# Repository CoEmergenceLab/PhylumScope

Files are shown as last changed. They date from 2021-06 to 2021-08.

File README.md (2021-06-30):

Banner

# Mechanical Design
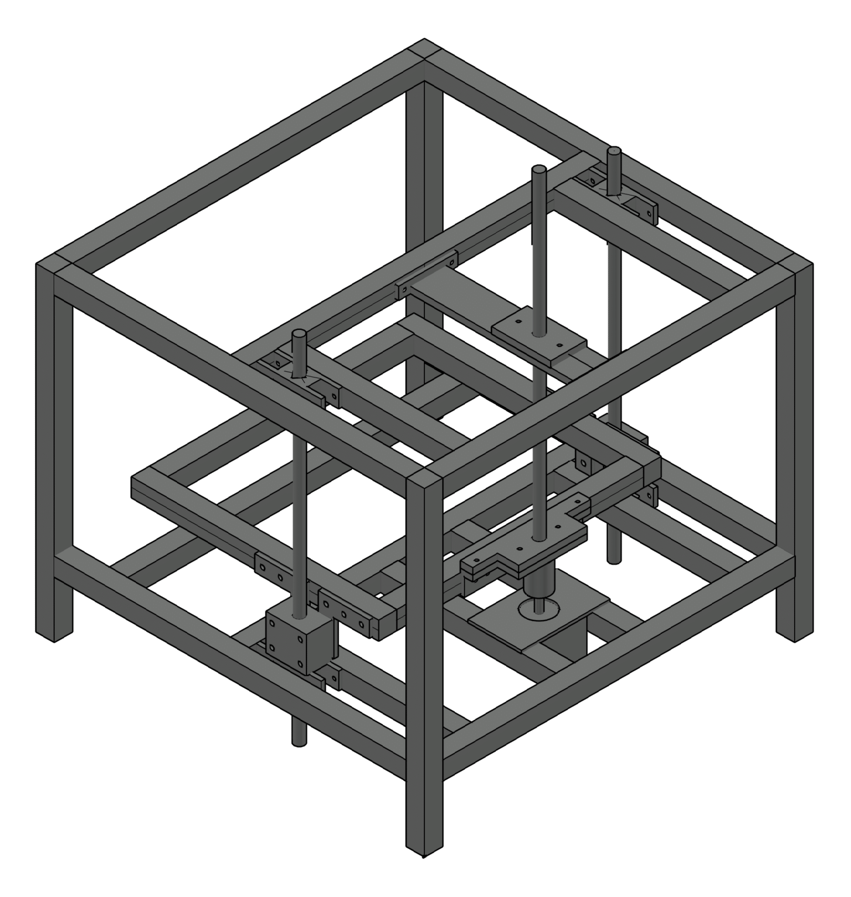
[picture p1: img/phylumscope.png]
Mechanical Design

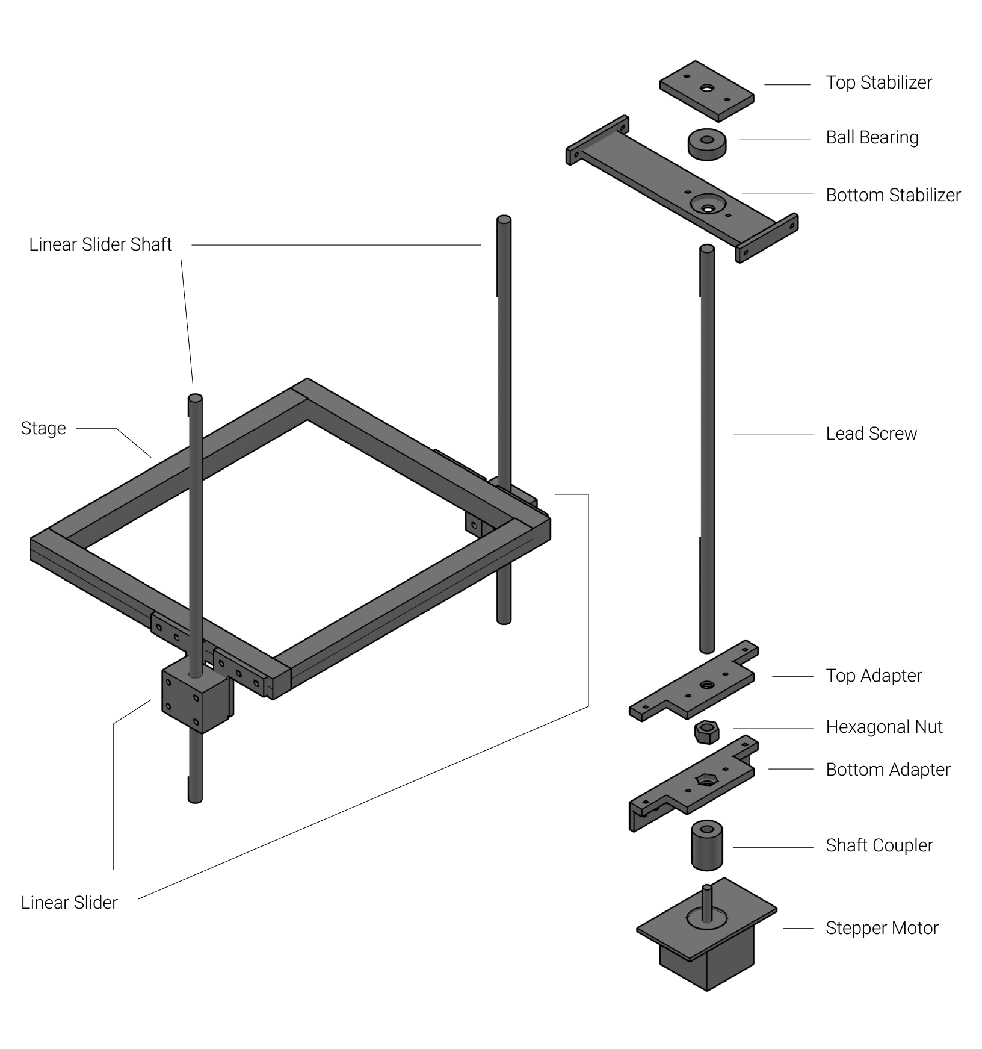
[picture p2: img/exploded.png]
Exploded View


# Electronics
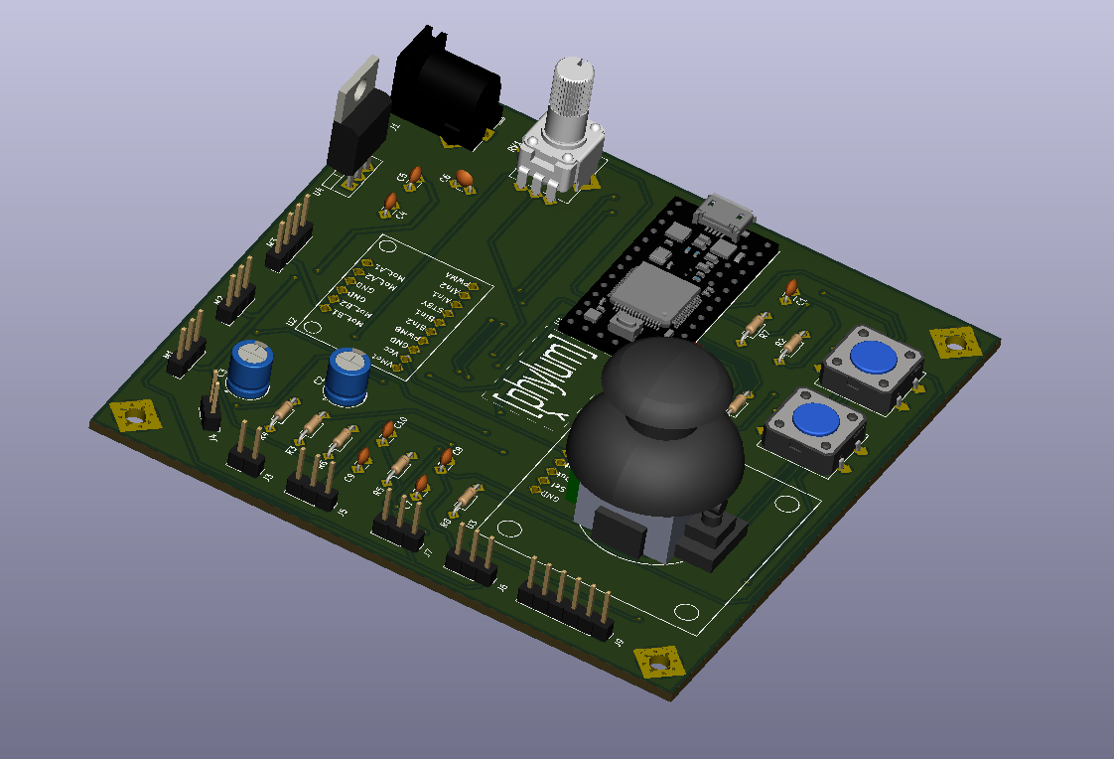
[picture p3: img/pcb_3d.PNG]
3D PCB

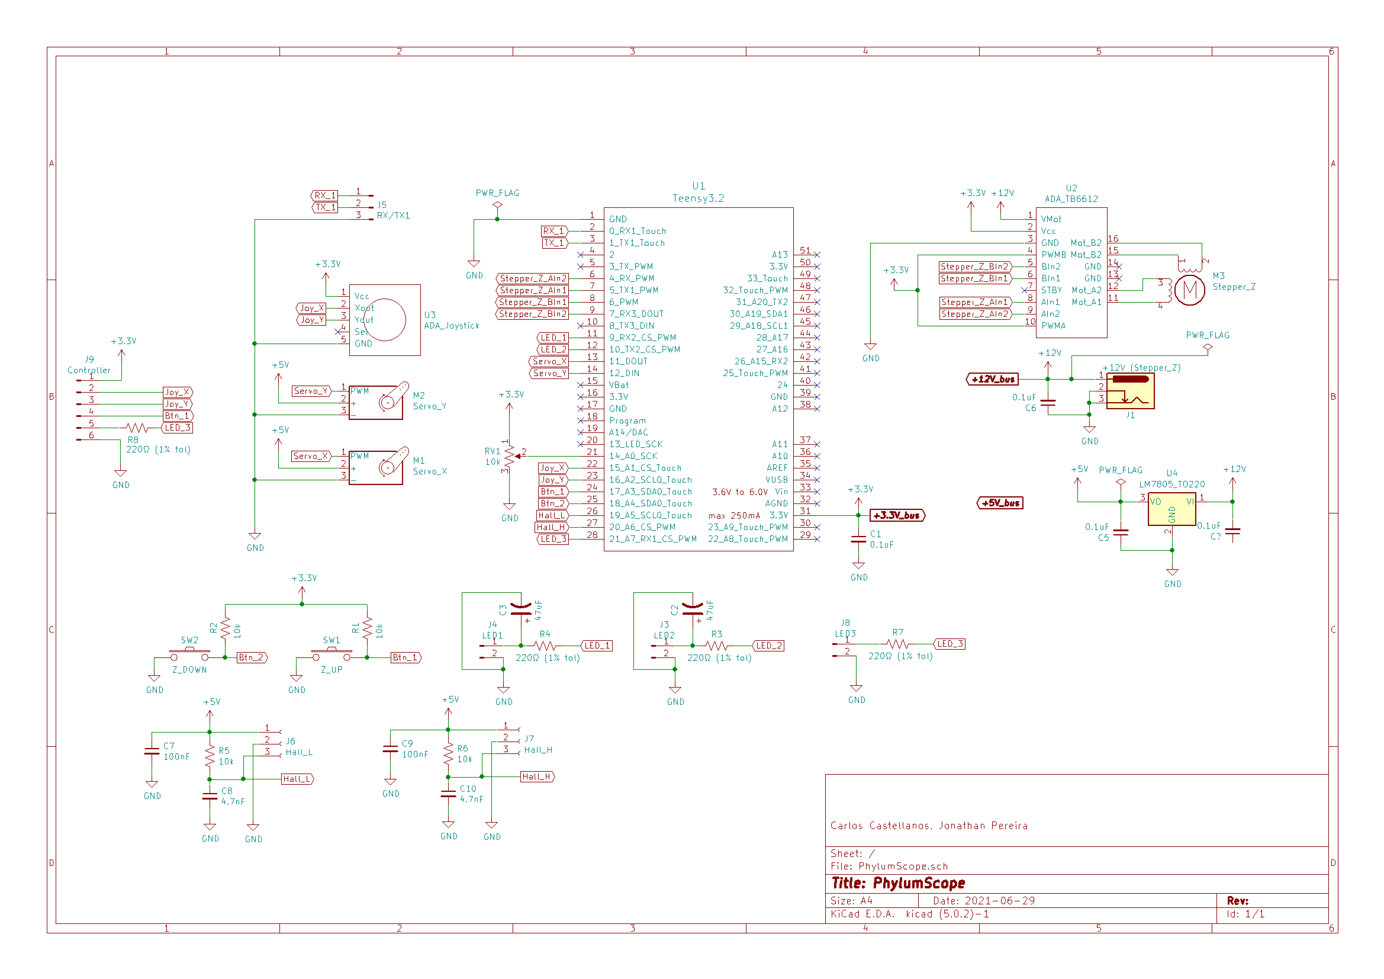
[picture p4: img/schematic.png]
Schematic

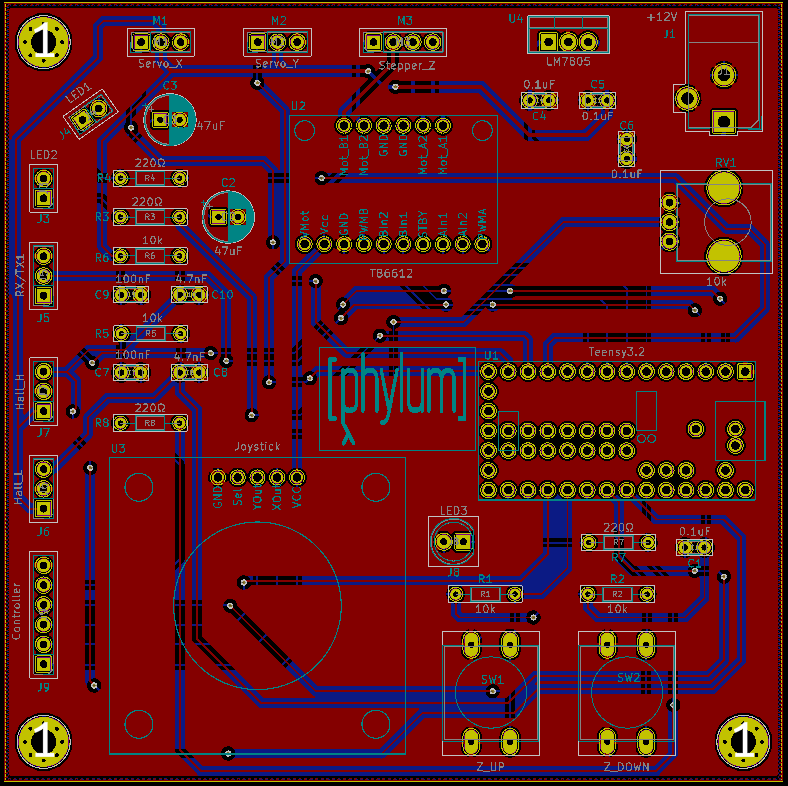
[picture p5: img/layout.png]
Layout


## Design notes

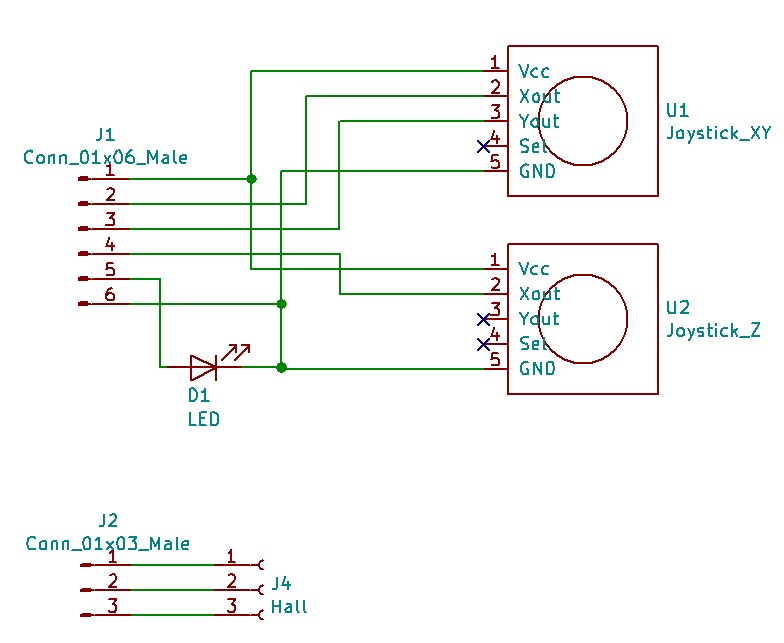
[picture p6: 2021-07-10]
img/breakouts_schematic.png

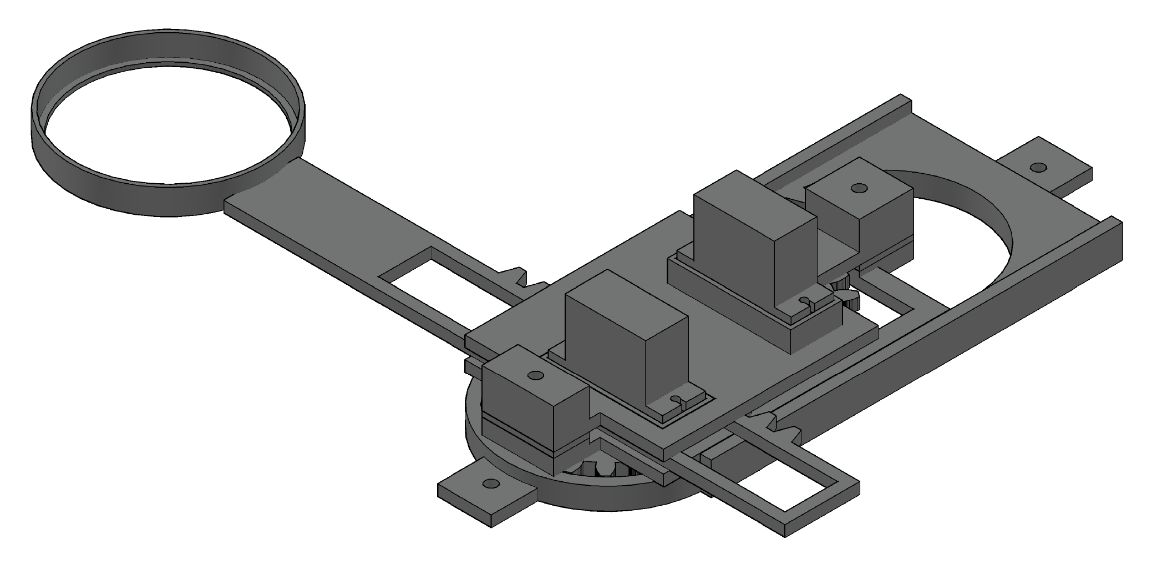
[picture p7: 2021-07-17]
img/xy.png

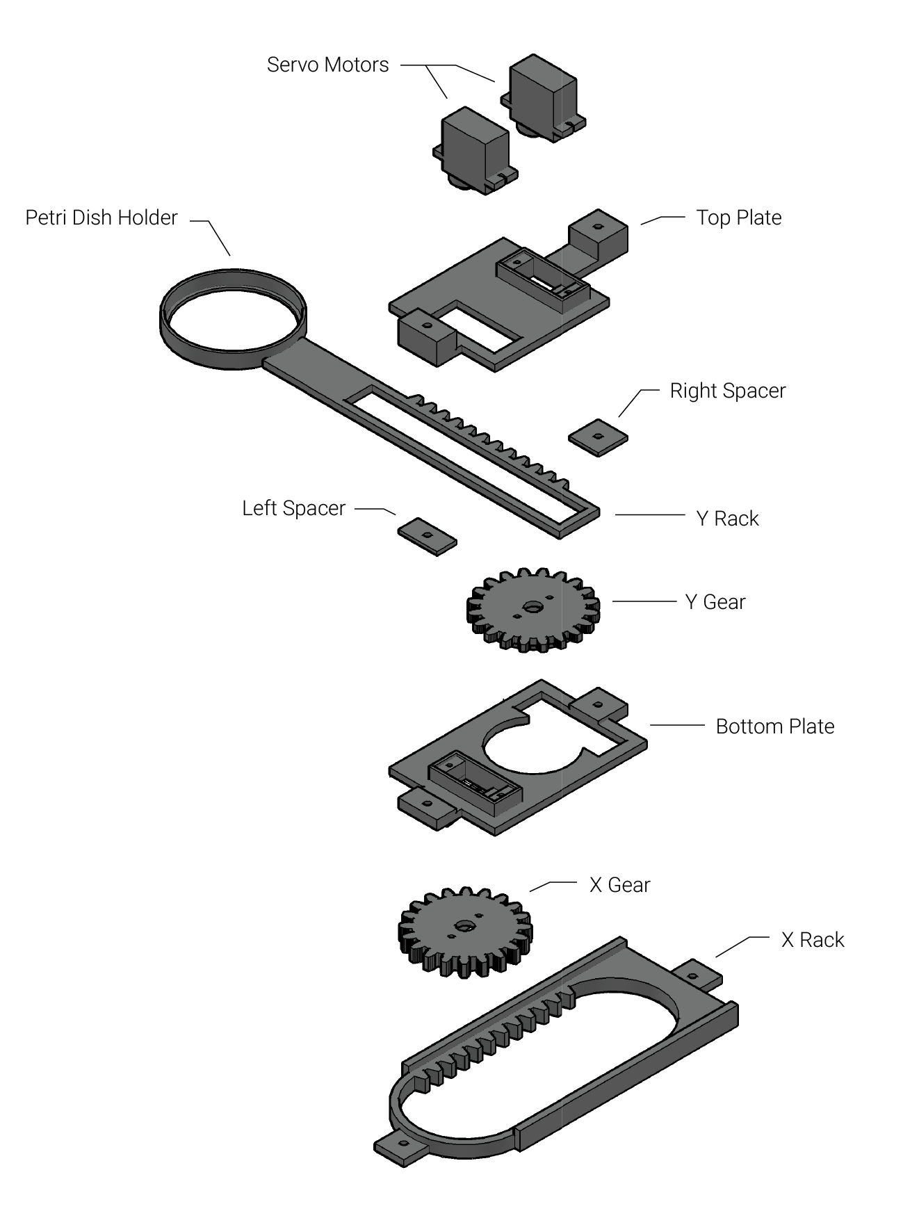
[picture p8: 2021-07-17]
img/xy_exploded.png

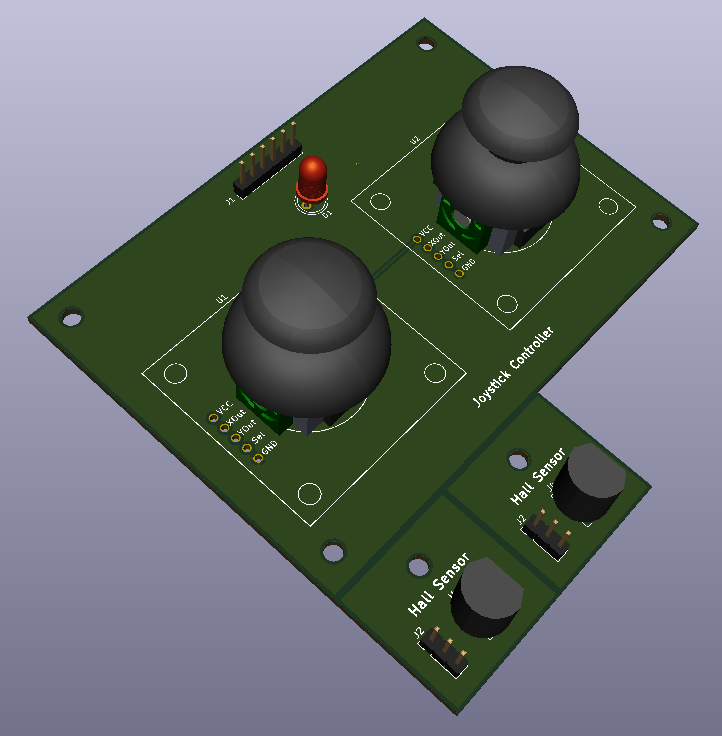
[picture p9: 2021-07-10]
img/breakouts_pcb_3d.PNG

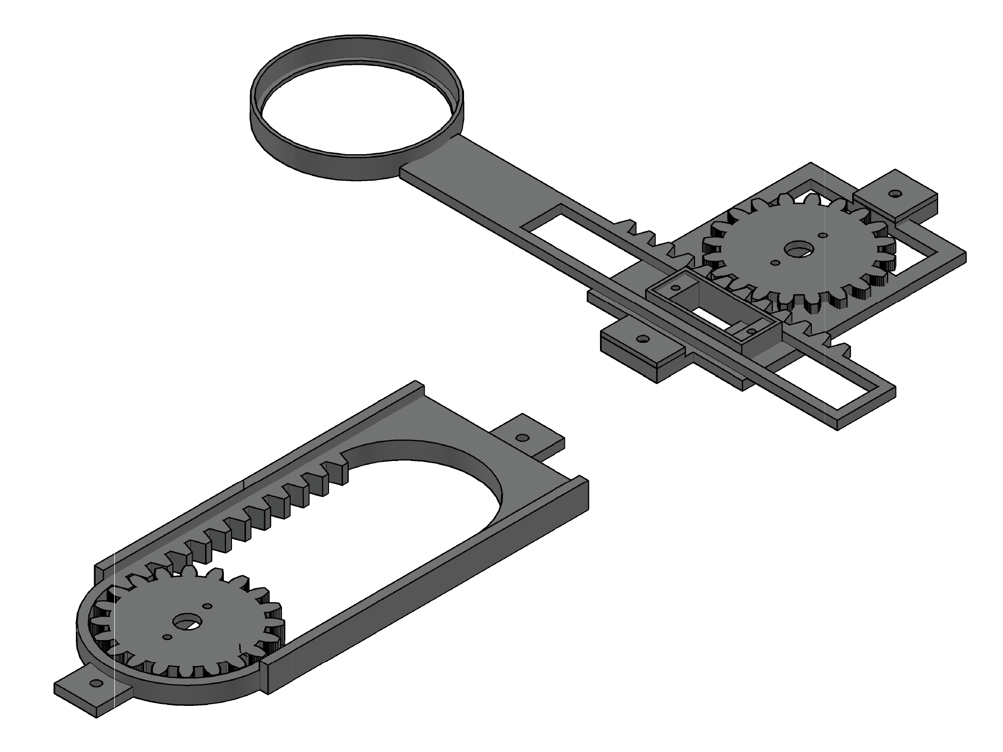
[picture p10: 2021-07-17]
img/xy_axis.png

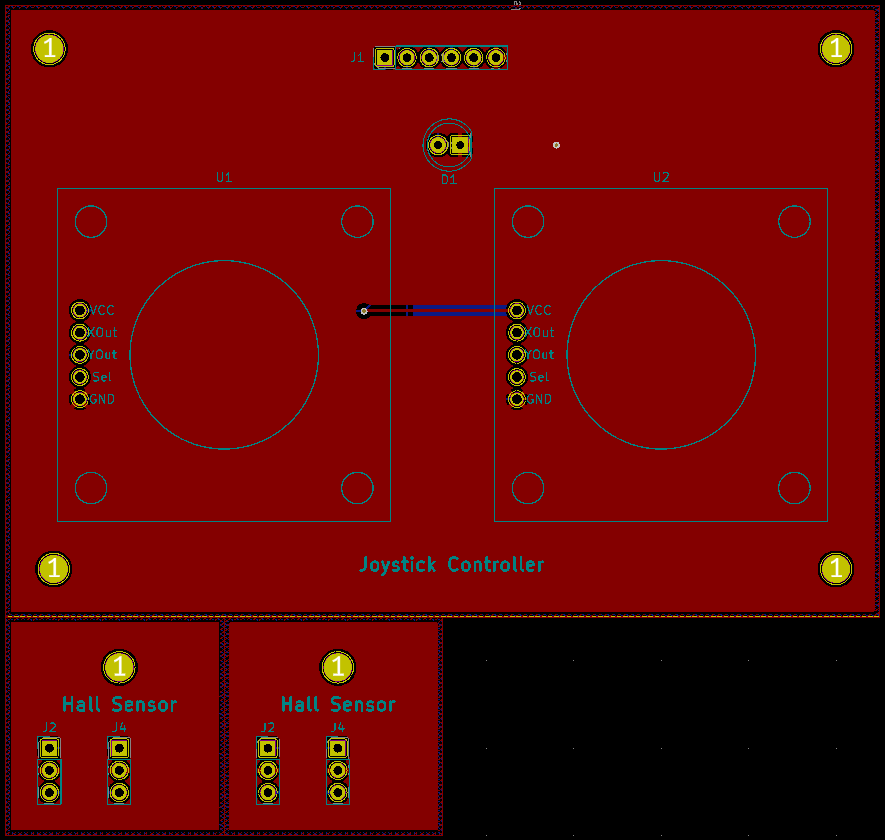
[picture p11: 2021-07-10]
img/breakouts_layout.png

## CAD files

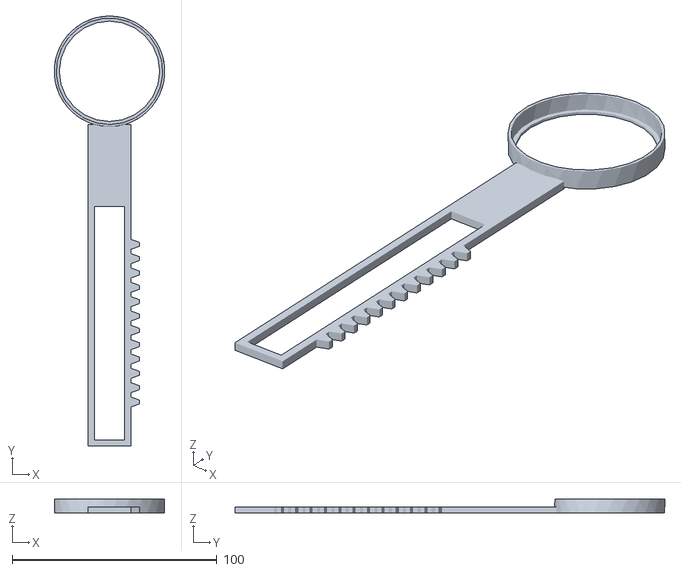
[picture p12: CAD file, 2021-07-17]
CAD/STL/XY/Y_Rack.stl
53.9 x 210.0 x 7.00

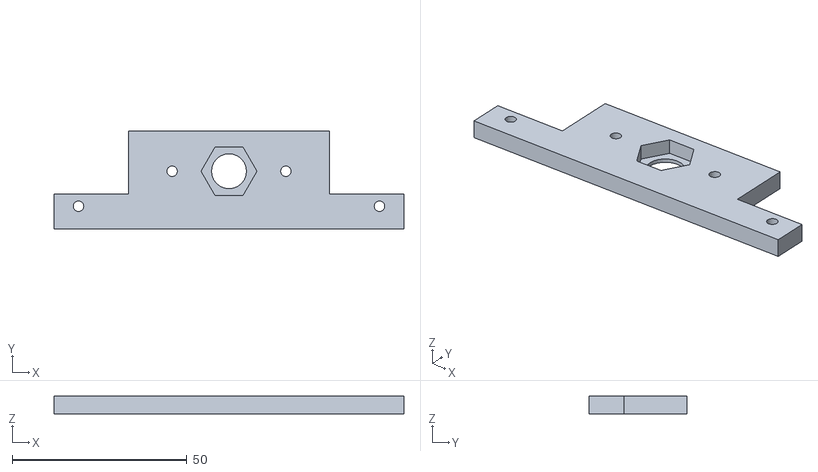
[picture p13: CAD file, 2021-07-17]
CAD/STL/Z/adapter_top.stl
100.0 x 28.0 x 5.00

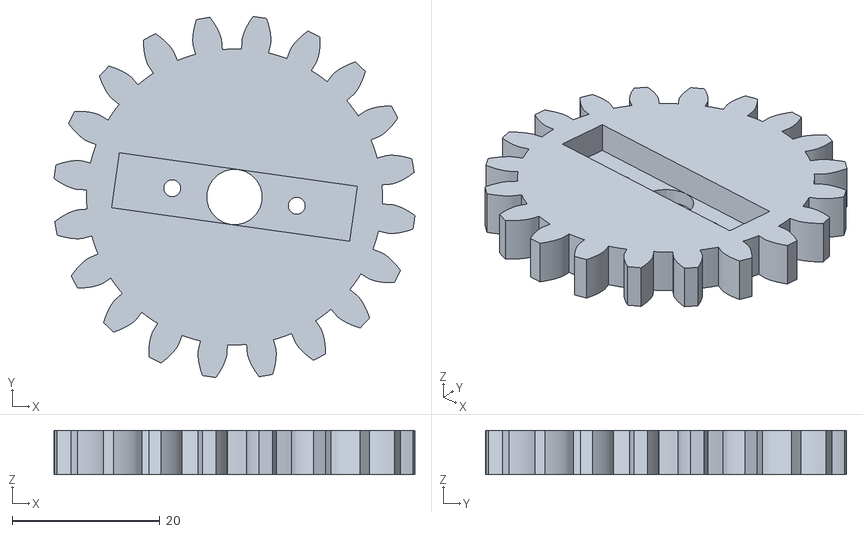
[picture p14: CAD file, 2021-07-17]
CAD/STL/XY/X_Gear.stl
48.8 x 48.8 x 6.00

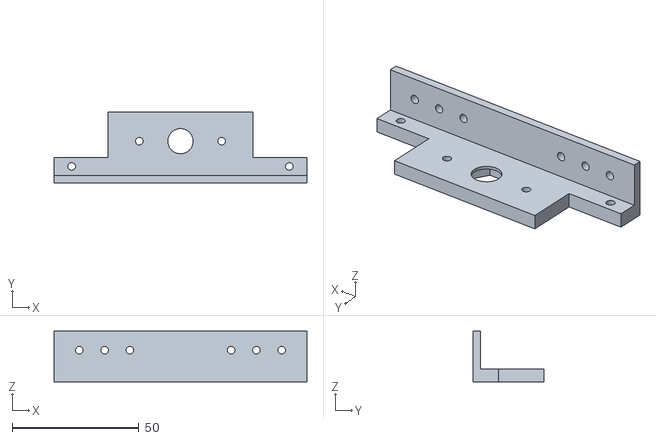
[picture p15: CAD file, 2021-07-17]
CAD/STL/Z/adapter_bottom.stl
100.0 x 28.0 x 20.0

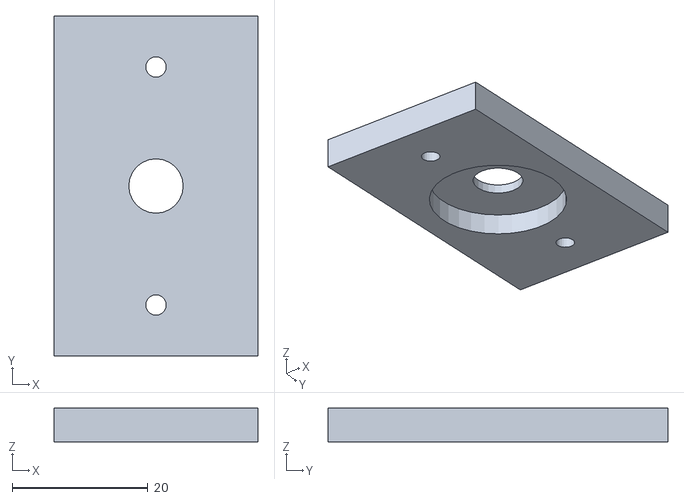
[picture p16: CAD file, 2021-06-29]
CAD/stabilizer_top.stl
30.0 x 50.0 x 5.00

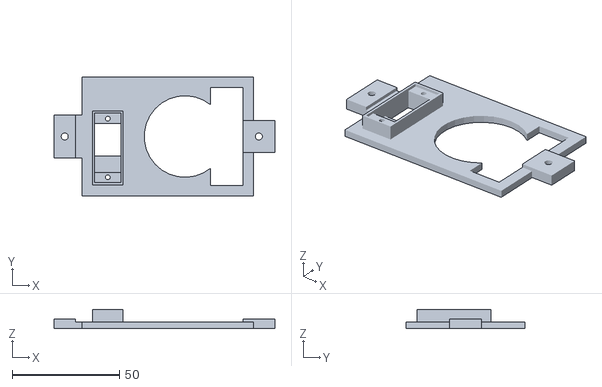
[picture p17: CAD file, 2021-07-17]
CAD/STL/XY/XY_Bottom.stl
103.0 x 55.5 x 9.00

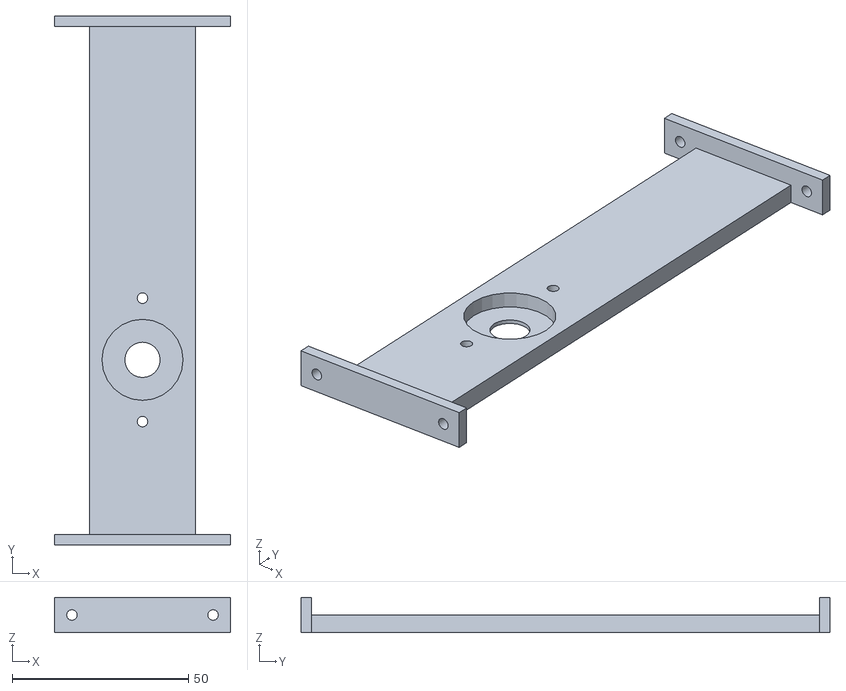
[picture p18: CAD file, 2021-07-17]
CAD/STL/Z/stabilizer_bottom.stl
50.0 x 150.0 x 10.0

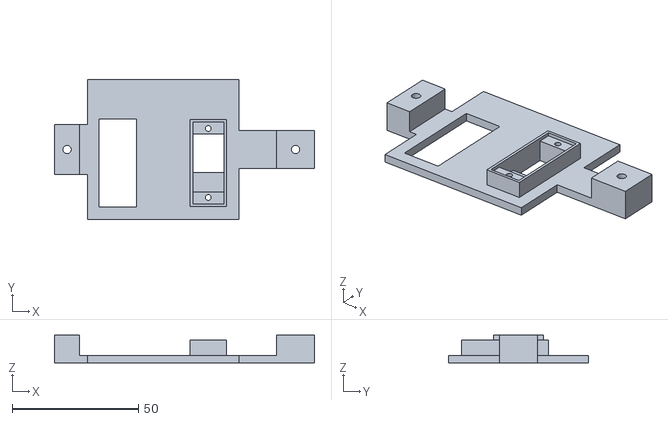
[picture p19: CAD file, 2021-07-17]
CAD/STL/XY/XY_Top.stl
103.0 x 55.5 x 11.0

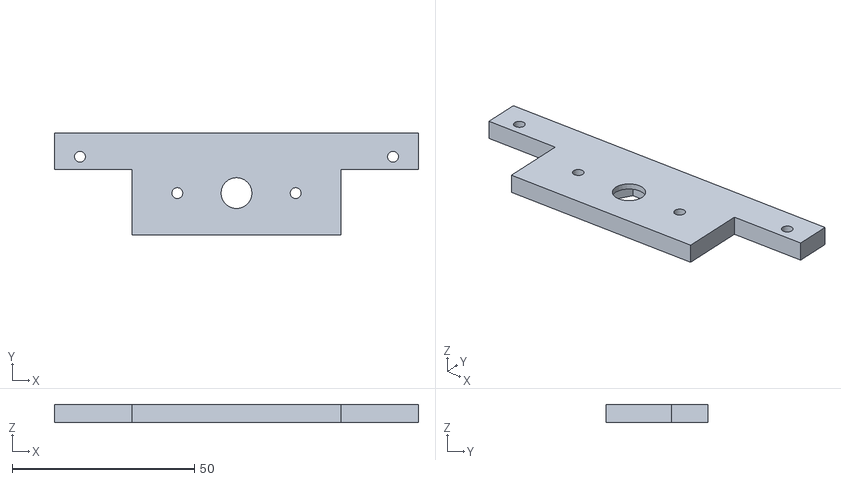
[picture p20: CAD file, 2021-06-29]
CAD/adapter_top.stl
100.0 x 28.0 x 5.00

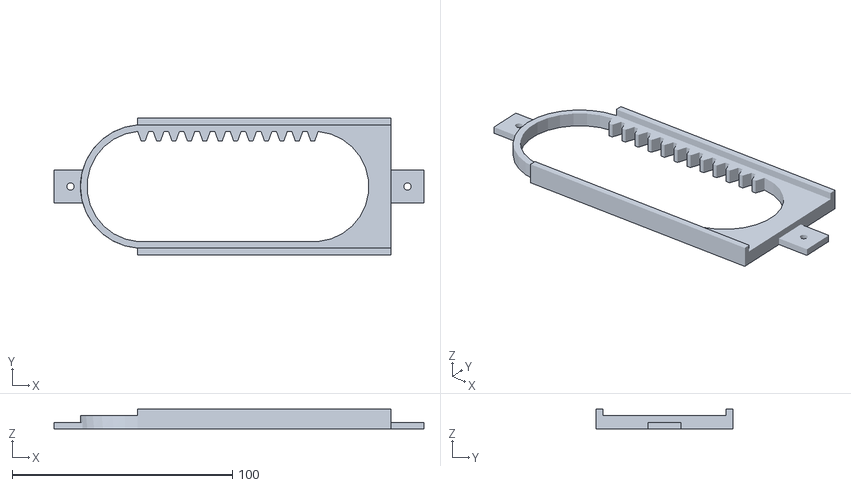
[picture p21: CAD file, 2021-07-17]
CAD/STL/XY/X_Rack.stl
168.0 x 62.0 x 9.00

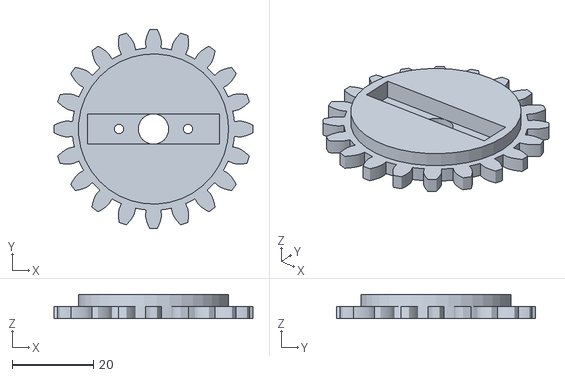
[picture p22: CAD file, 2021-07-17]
CAD/STL/XY/Y_Gear.stl
49.0 x 49.0 x 6.00

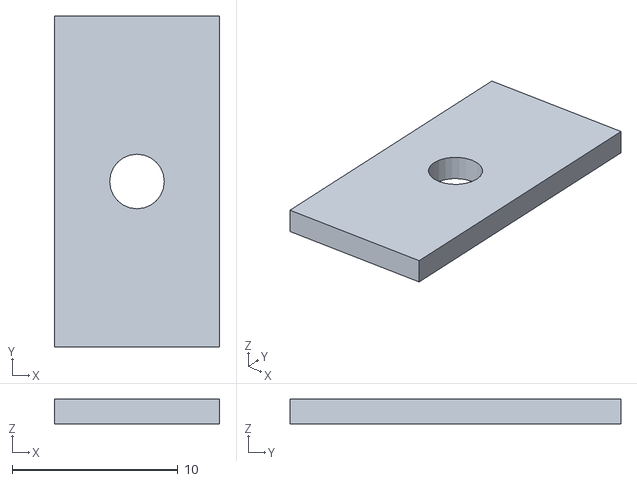
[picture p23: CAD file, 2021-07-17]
CAD/STL/XY/Spacer_L.stl
10.00 x 20.0 x 1.50

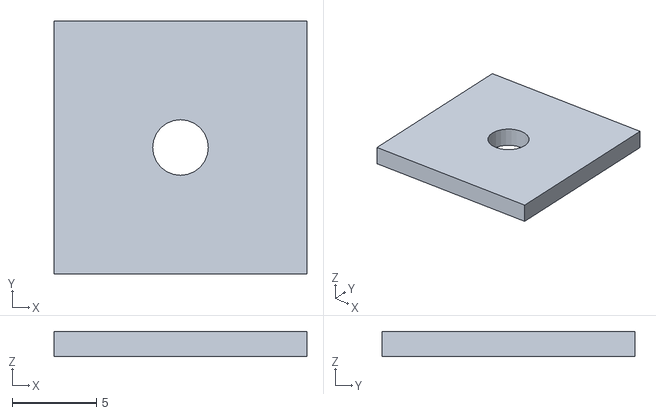
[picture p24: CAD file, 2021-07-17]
CAD/STL/XY/Spacer_R.stl
15.0 x 15.0 x 1.50

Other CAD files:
CAD/phylumscope.dwg
CAD/phylum_xy.dwg
CAD/stabilizer_bottom.stl
CAD/STL/Z/stabilizer_top.stl
CAD/adapter_bottom.stl

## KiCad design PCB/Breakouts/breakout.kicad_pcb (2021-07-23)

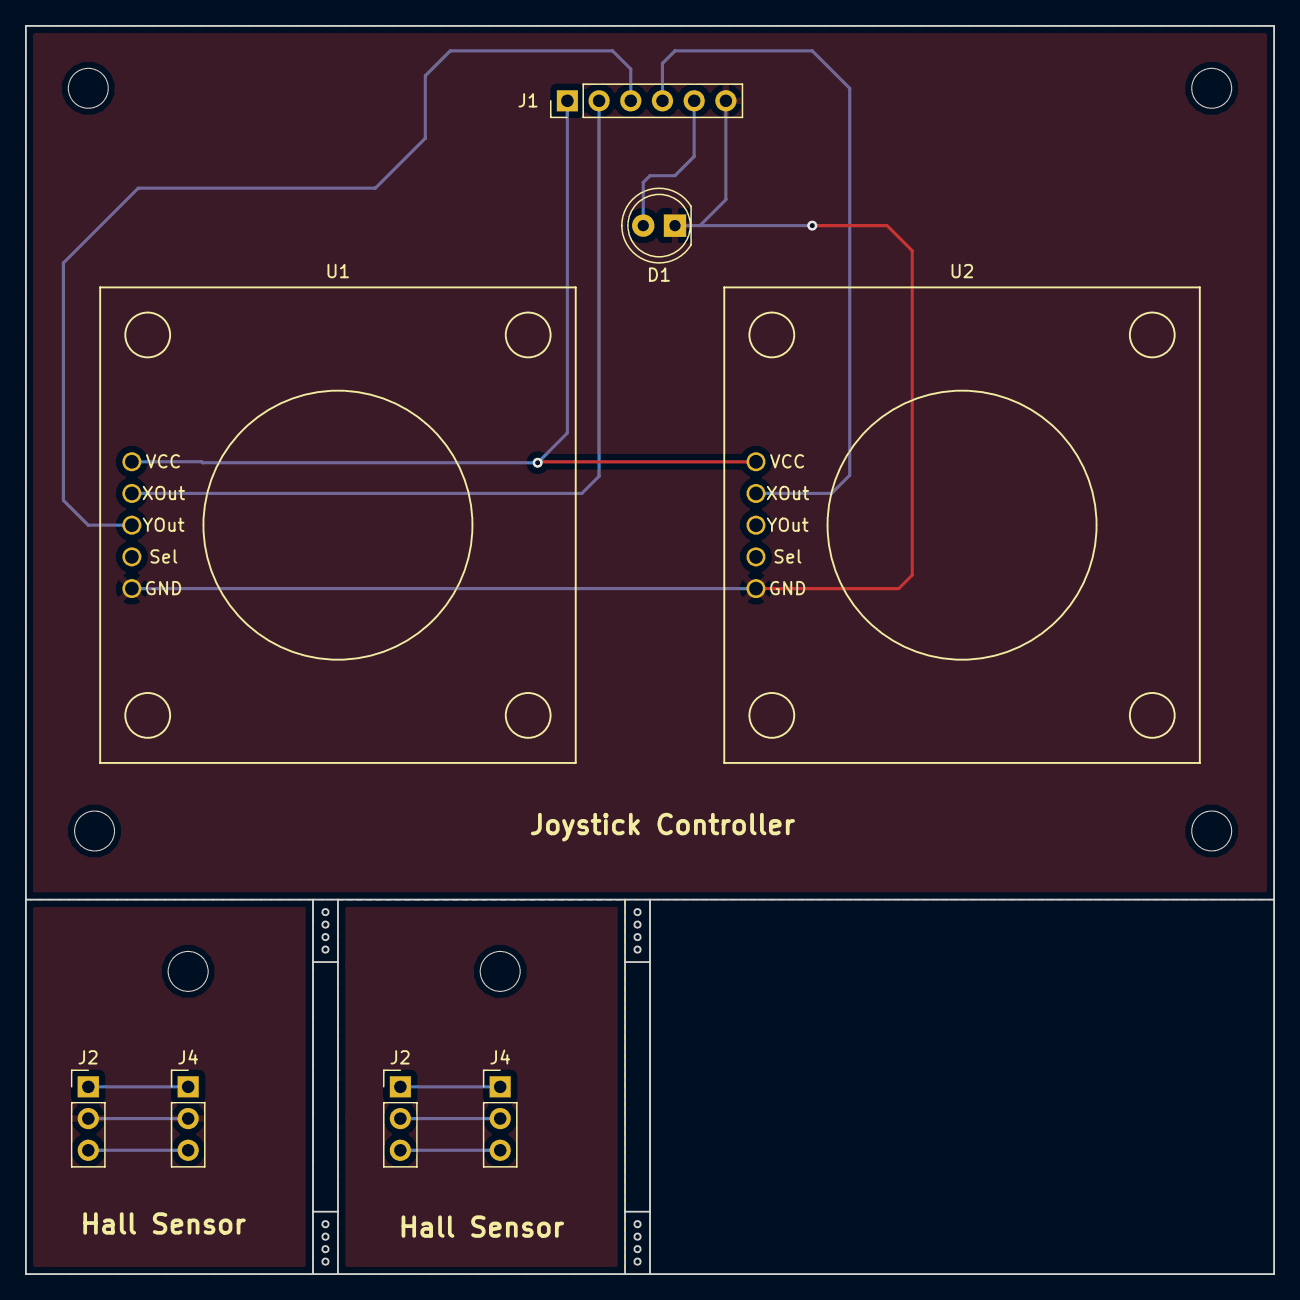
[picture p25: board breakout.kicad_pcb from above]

Board: 2 copper layers, 100.0 x 100.0 mm, 8 parts (0 on the bottom side), 9 nets.

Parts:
D1: LED; LED_D5.0mm
J1: PinHeader_1x06_P2.54mm_Vertical
J2, J2#2: PinHeader_1x03_P2.54mm_Vertical
J4, J4#2: Hall; PinHeader_1x03_P2.54mm_Vertical
U1: Joystick_XY; ADA_joystick
U2: Joystick_Z; ADA_joystick

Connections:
unnamed: D1.1, J1.6, U1.5, U2.5
unnamed: D1.2, J1.5
unnamed: J1.1, U1.1, U2.1
unnamed: J1.2, U1.2
unnamed: J1.3, U1.3
unnamed: J1.4, U2.2
unnamed: J2#2.1, J4#2.1
unnamed: J2#2.2, J4#2.2
unnamed: J2#2.3, J4#2.3

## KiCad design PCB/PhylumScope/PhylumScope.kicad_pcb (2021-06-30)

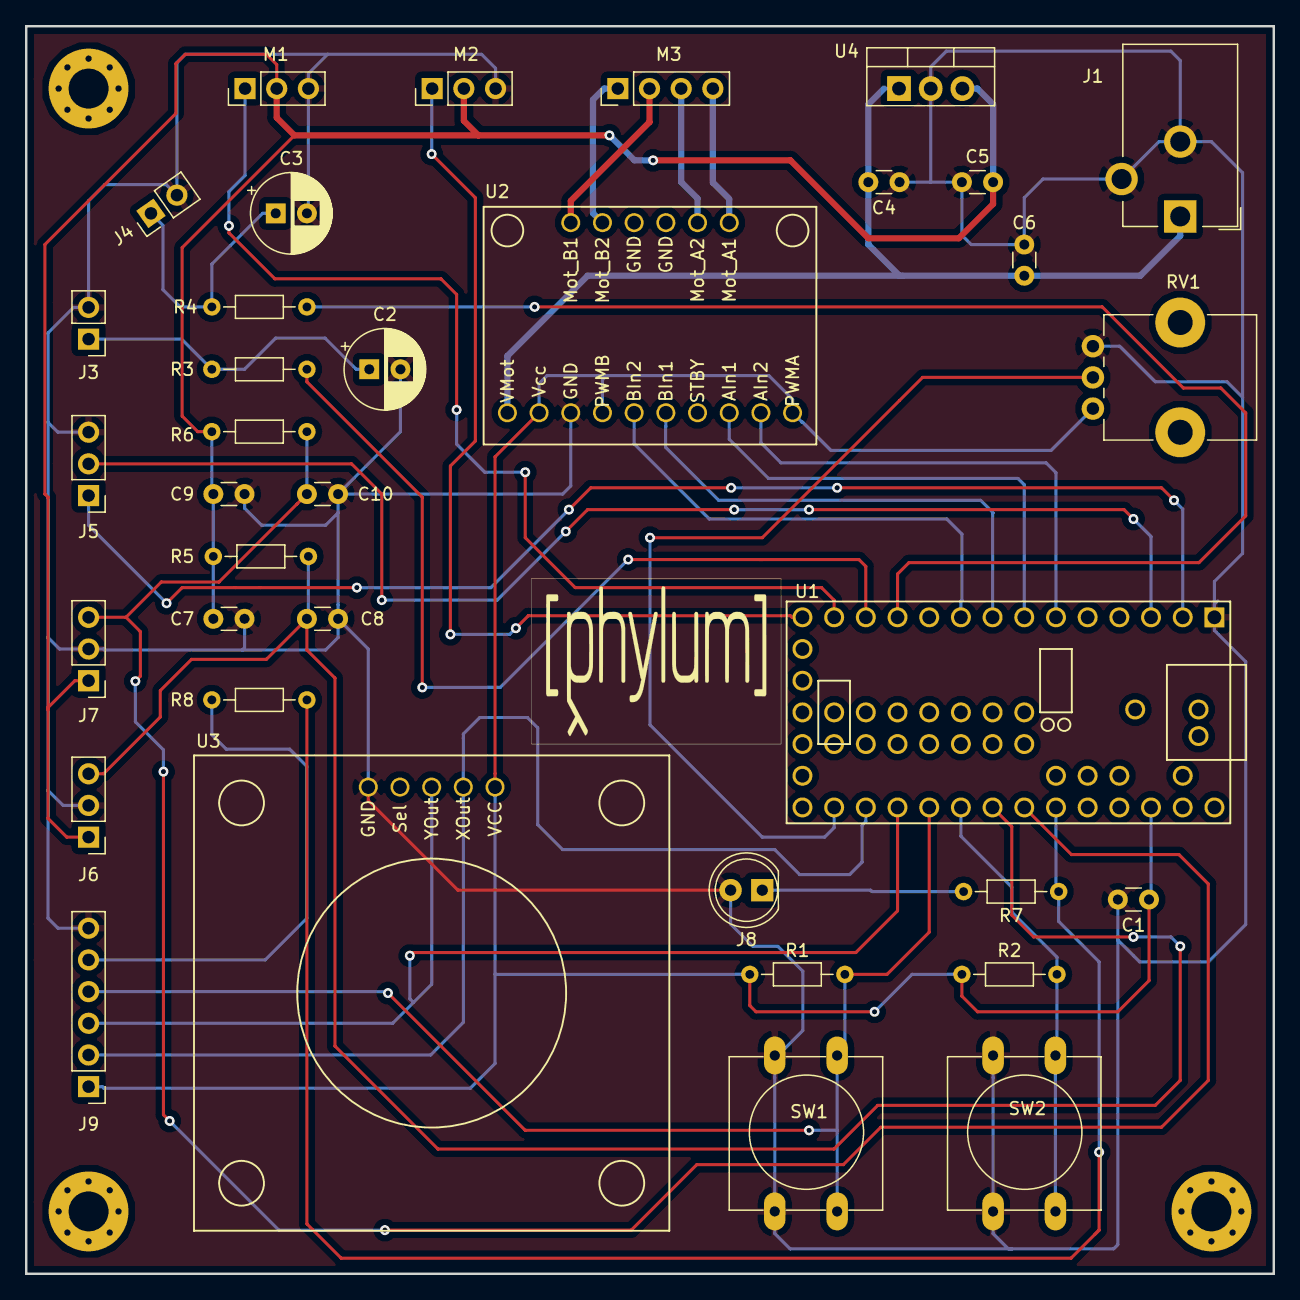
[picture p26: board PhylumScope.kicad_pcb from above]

Board: 2 copper layers, 100.0 x 100.0 mm, 36 parts (0 on the bottom side), 30 nets.

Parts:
C1, C4, C5, C6: 0.1uF; C_Disc_D3.0mm_W1.6mm_P2.50mm
C2, C3: 47uF; CP_Radial_D6.3mm_P2.50mm
C7, C9: 100nF; C_Disc_D3.0mm_W1.6mm_P2.50mm
C8, C10: 4.7nF; C_Disc_D3.0mm_W1.6mm_P2.50mm
J1: +12V; BarrelJack_CUI_PJ-102AH_Horizontal
J3: LED2; PinHeader_1x02_P2.54mm_Vertical
J4: LED1; PinHeader_1x02_P2.54mm_Vertical
J5: RX/TX1; PinHeader_1x03_P2.54mm_Vertical
J6: Hall_L; PinHeader_1x03_P2.54mm_Vertical
J7: Hall_H; PinHeader_1x03_P2.54mm_Vertical
J8: LED3; LED_D5.0mm
J9: Controller; PinHeader_1x06_P2.54mm_Vertical
M1: Servo_X; PinHeader_1x03_P2.54mm_Vertical
M2: Servo_Y; PinHeader_1x03_P2.54mm_Vertical
M3: Stepper_Z; PinHeader_1x04_P2.54mm_Vertical
R1, R2, R5, R6: 10k; R_Axial_DIN0204_L3.6mm_D1.6mm_P7.62mm_Horizontal
R3, R4, R7, R8: 220Ω; R_Axial_DIN0204_L3.6mm_D1.6mm_P7.62mm_Horizontal
RV1: 10k; Potentiometer_Alps_RK09K_Single_Vertical
SW1: Z_UP; SW_PUSH-12mm
SW2: Z_DOWN; SW_PUSH-12mm
U1: Teensy3.2; Teensy30_31_32_All_Pins
U2: TB6612; ADA_TB6612
U3: Joystick; ADA_joystick
U4: LM7805; TO-220-3_Vertical

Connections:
+3.3V_bus: C1.1, J9.1, R1.1, R2.1, RV1.1, U1.31, U2.2, U2.4, U2.10, U3.1
+5V_bus: C5.2, C7.1, C9.1, J6.1, J7.1, M1.2, M2.2, R5.1, R6.1, U4.3
+12V_bus: C4.2, C6.2, J1.1, U2.1, U4.1
Btn_1: J9.4, R1.2, SW1.2, U1.24
Btn_2: R2.2, SW2.2, U1.25
GND: C1.2, C2.2, C3.2, C4.1, C5.1, C6.1, C7.2, C8.2, C9.2, C10.2, J1.2, J1.3, J3.2, J4.2, J5.3, J6.2, J7.2, J8.2, J9.6, M1.3, M2.3, RV1.3, SW1.1, SW2.1, U1.1, U2.3, U3.5, U4.2
Hall_H: C10.1, J7.3, R6.2, U1.27
Hall_L: C8.1, J6.3, R5.2, U1.26
Joy_X: J9.2, U1.22, U3.2
Joy_Y: J9.3, U1.23, U3.3
LED_1: R4.1, U1.11
LED_2: R3.1, U1.12
LED_3: R7.1, R8.1, U1.28
unnamed: C2.1, J3.1, R3.2
unnamed: C3.1, J4.1, R4.2
unnamed: J8.1, R7.2
unnamed: J9.5, R8.2
unnamed: M3.1, U2.15
unnamed: M3.2, U2.16
unnamed: M3.3, U2.12
unnamed: M3.4, U2.11
unnamed: RV1.2, U1.21
RX_1: J5.1, U1.2
Servo_X: M1.1, U1.13
Servo_Y: M2.1, U1.14
Stepper_Z_AIn1: U1.7, U2.8
Stepper_Z_AIn2: U1.6, U2.9
Stepper_Z_BIn1: U1.8, U2.6
Stepper_Z_BIn2: U1.9, U2.5
TX_1: J5.2, U1.3

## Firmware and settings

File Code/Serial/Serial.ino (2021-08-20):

String COM_X = "COM_X";
String COM_Y = "COM_Y";
String COM_Z = "COM_Z";
String ACK_X = "ACK_X";
String ACK_Y = "ACK_Y";
String ACK_Z = "ACK_Z";

void setup(){
  Serial.begin(9600);
}

void loop(){
  if (Serial.available() > 0){  // Check if there is data available to read from the Serial port.
    String s_com = (Serial.readStringUntil("/r"));
    if(s_com == COM_X){
      Serial.println(ACK_X);
      while(1){
        if (Serial.available() > 0){  // Check if there is data available to read from the Serial port.
          String s_xval = (Serial.readStringUntil("/r"));
          int xval = s_xval.toInt();
          Serial.print("X: ");
          Serial.println(xval);
          delay(100);
          Serial.println(ACK_X);
          break; 
        }
      }
    }
    if (s_com == COM_Y){
      Serial.println(ACK_Y);
      while(1){
        if (Serial.available() > 0){  // Check if there is data available to read from the Serial port.
          String s_yval = (Serial.readStringUntil("/r"));
          int yval = s_yval.toInt();
          Serial.print("Y: ");
          Serial.println(yval);
          delay(100);
          Serial.println(ACK_Y);
          break; 
        }
      }
    }
    if (s_com == COM_Z){
      Serial.println(ACK_Z);
      while(1){
        if (Serial.available() > 0){  // Check if there is data available to read from the Serial port.
          String s_zval = (Serial.readStringUntil("/r"));
          int zval = s_zval.toInt();
          Serial.print("Z: ");
          Serial.println(zval);
          delay(100);
          Serial.println(ACK_Z);
          break; 
        }
      }
    }
  }
}

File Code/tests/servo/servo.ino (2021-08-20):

#include <Servo.h>


#define SERVO_X (11)
#define SERVO_Y (12)

Servo servo_x;
Servo servo_y;

int pos;
void setup()
{
  Serial.begin(9600);
  servo_x.attach(SERVO_X);
  servo_y.attach(SERVO_Y);
}

void loop()
{
  servo_x.write(0);              // tell servo to go to position in variable 'pos'
  servo_y.write(0);
  for(pos = 0; pos <= 180; pos += 1) // goes from 0 degrees to 180 degrees 
  {                                  // in steps of 1 degree 
    servo_x.write(pos);              // tell servo to go to position in variable 'pos'
    servo_y.write(pos); 
    delay(15);                       // waits 15ms for the servo to reach the position 
  } 
  for(pos = 180; pos>=0; pos-=1)     // goes from 180 degrees to 0 degrees 
  {                                
    servo_x.write(pos);              // tell servo to go to position in variable 'pos'
    servo_y.write(pos);
    delay(15);                       // waits 15ms for the servo to reach the position 
  } 
}

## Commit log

2021-06-29 CAD design, STL files
    - AutoCAD design.
    - STL files for 3D printed adapter and stabilizer parts.
    - Design does not include Microscope attachment.
    [adapter_bottom.stl, adapter_top.stl, phylumscope.dwg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]
2021-06-30 PCB Libraries
2021-06-30 KiCAD - Schematic, Layout
    [PhylumScope.kicad_pcb, PhylumScope.sch]
2021-07-08 XY axis
    Under Construction: Yrack, Yrack base, Yrack top.
    Completed: Xgear, Xrack, Ygear, servo arm.
    [phylum_xy.dwg]
2021-07-10 Breakout Boards - KiCad
    - Schematic, Layout and 3D file for external controller and hall effect sensors
    [breakout.kicad_pcb, breakout.sch]
2021-07-10 PCB gerber files
    - Main board
    - Breakout boards
    [PhylumScope-B.Cu.gbr, PhylumScope-B.Mask.gbr, PhylumScope-B.Paste.gbr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]
2021-07-17 Z-axis improved tolerances
    [adapter_bottom.stl, adapter_top.stl, phylumscope.dwg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]
2021-07-17 XY axis
    [Spacer_L.stl, Spacer_R.stl, XY_Bottom.stl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]
2021-07-23 Breakouts V-Cut update, Zipped Gerbers
    [breakout-B.Cu.gbl, breakout-B.Mask.gbs, breakout-B.Paste.gbp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]
2021-08-20 Optical Flow
2021-08-20 Test programs for XY and Z axis
